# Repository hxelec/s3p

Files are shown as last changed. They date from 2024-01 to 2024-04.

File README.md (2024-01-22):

Haase Industries S3P boards: Arduino IDE code and KiCad schematic.

I'll comment the Arduino sketches properly in a few weeks, but,
meanwhile, ask me anything about the code or the schematic on my
YouTube video, and I'll be sure to respond to it.

Here's the video about this project:
https://youtu.be/9oY4NeJDy-g

Thanks to PCBWay for sponsoring this project! Get $5 of New User Free Credit by following this link - https://pcbway.com/g/x5f10h

PCBWay is one of the most experienced PCB manufacturers in China, consider them your one-stop solution that offers PCB fabrication, turn-key PCB Assembly, PCB design, 3D printing, and CNC machining services.

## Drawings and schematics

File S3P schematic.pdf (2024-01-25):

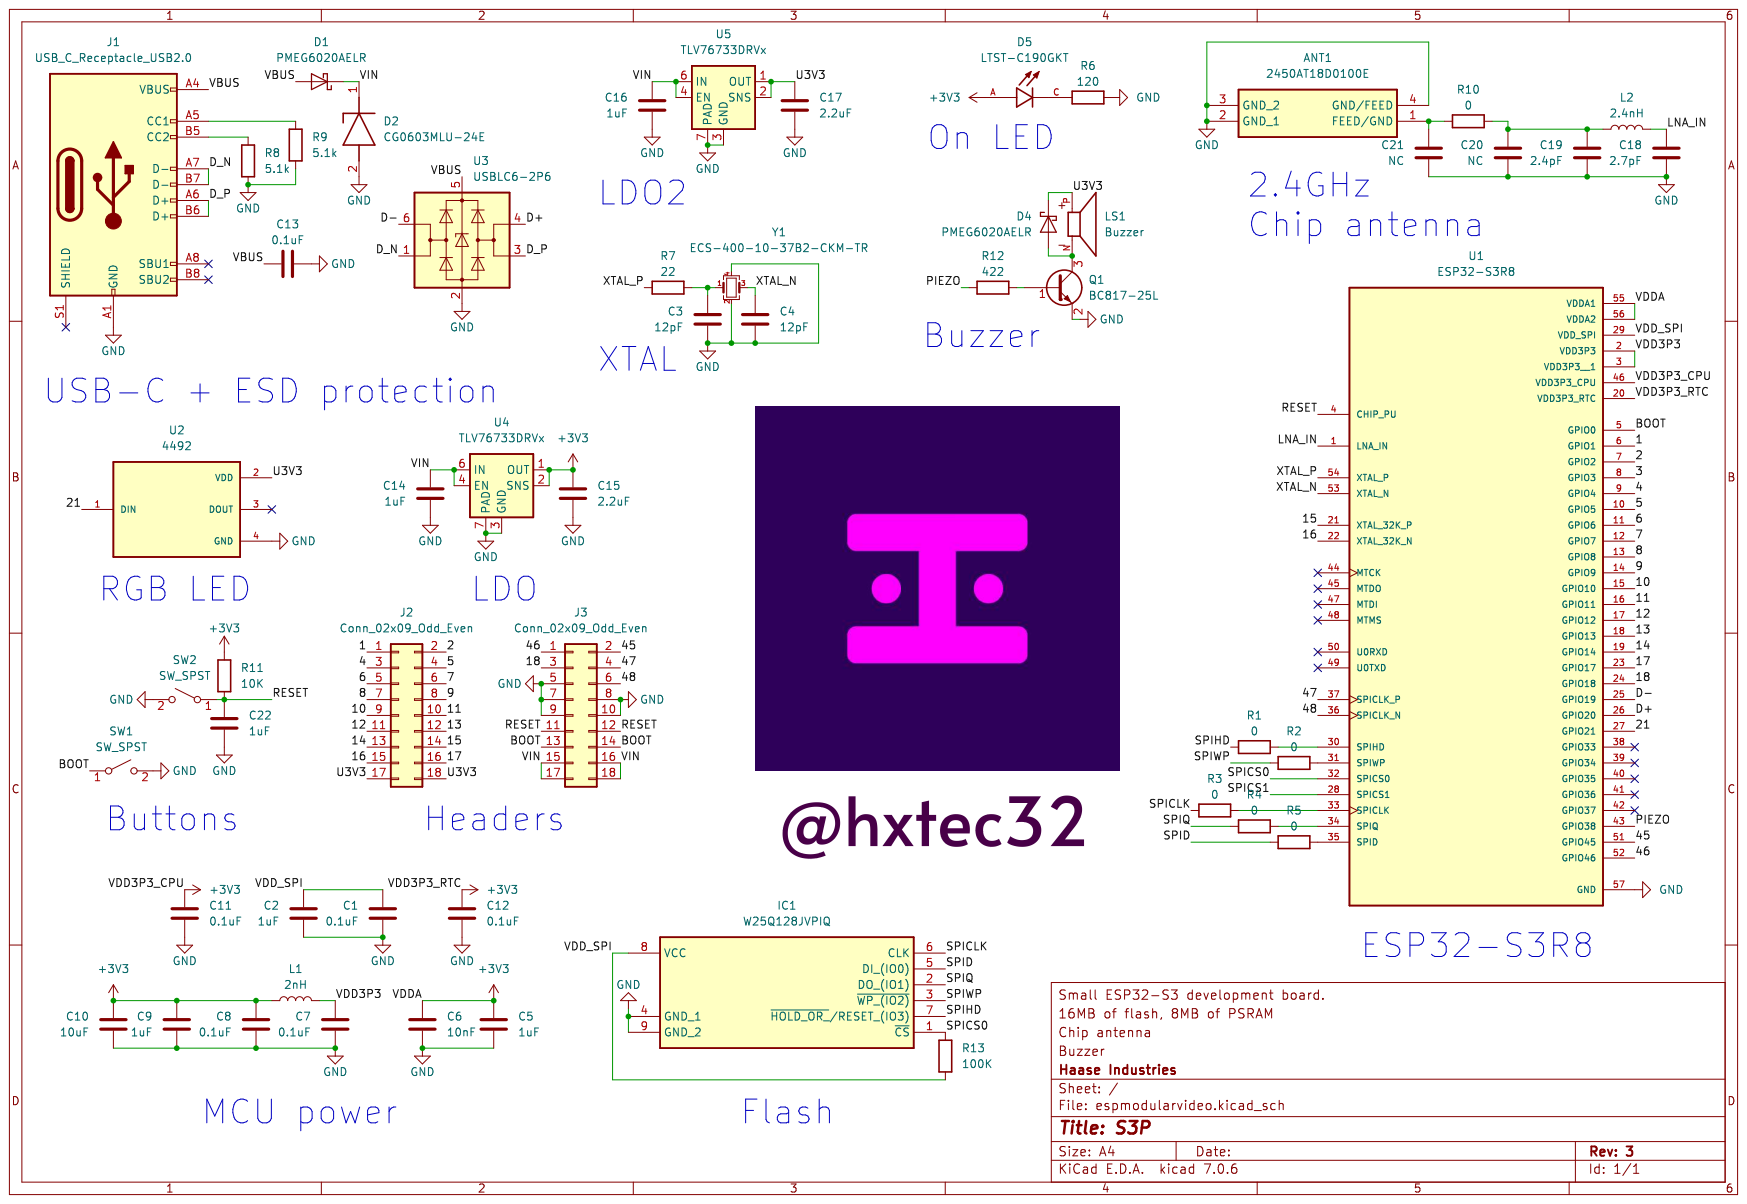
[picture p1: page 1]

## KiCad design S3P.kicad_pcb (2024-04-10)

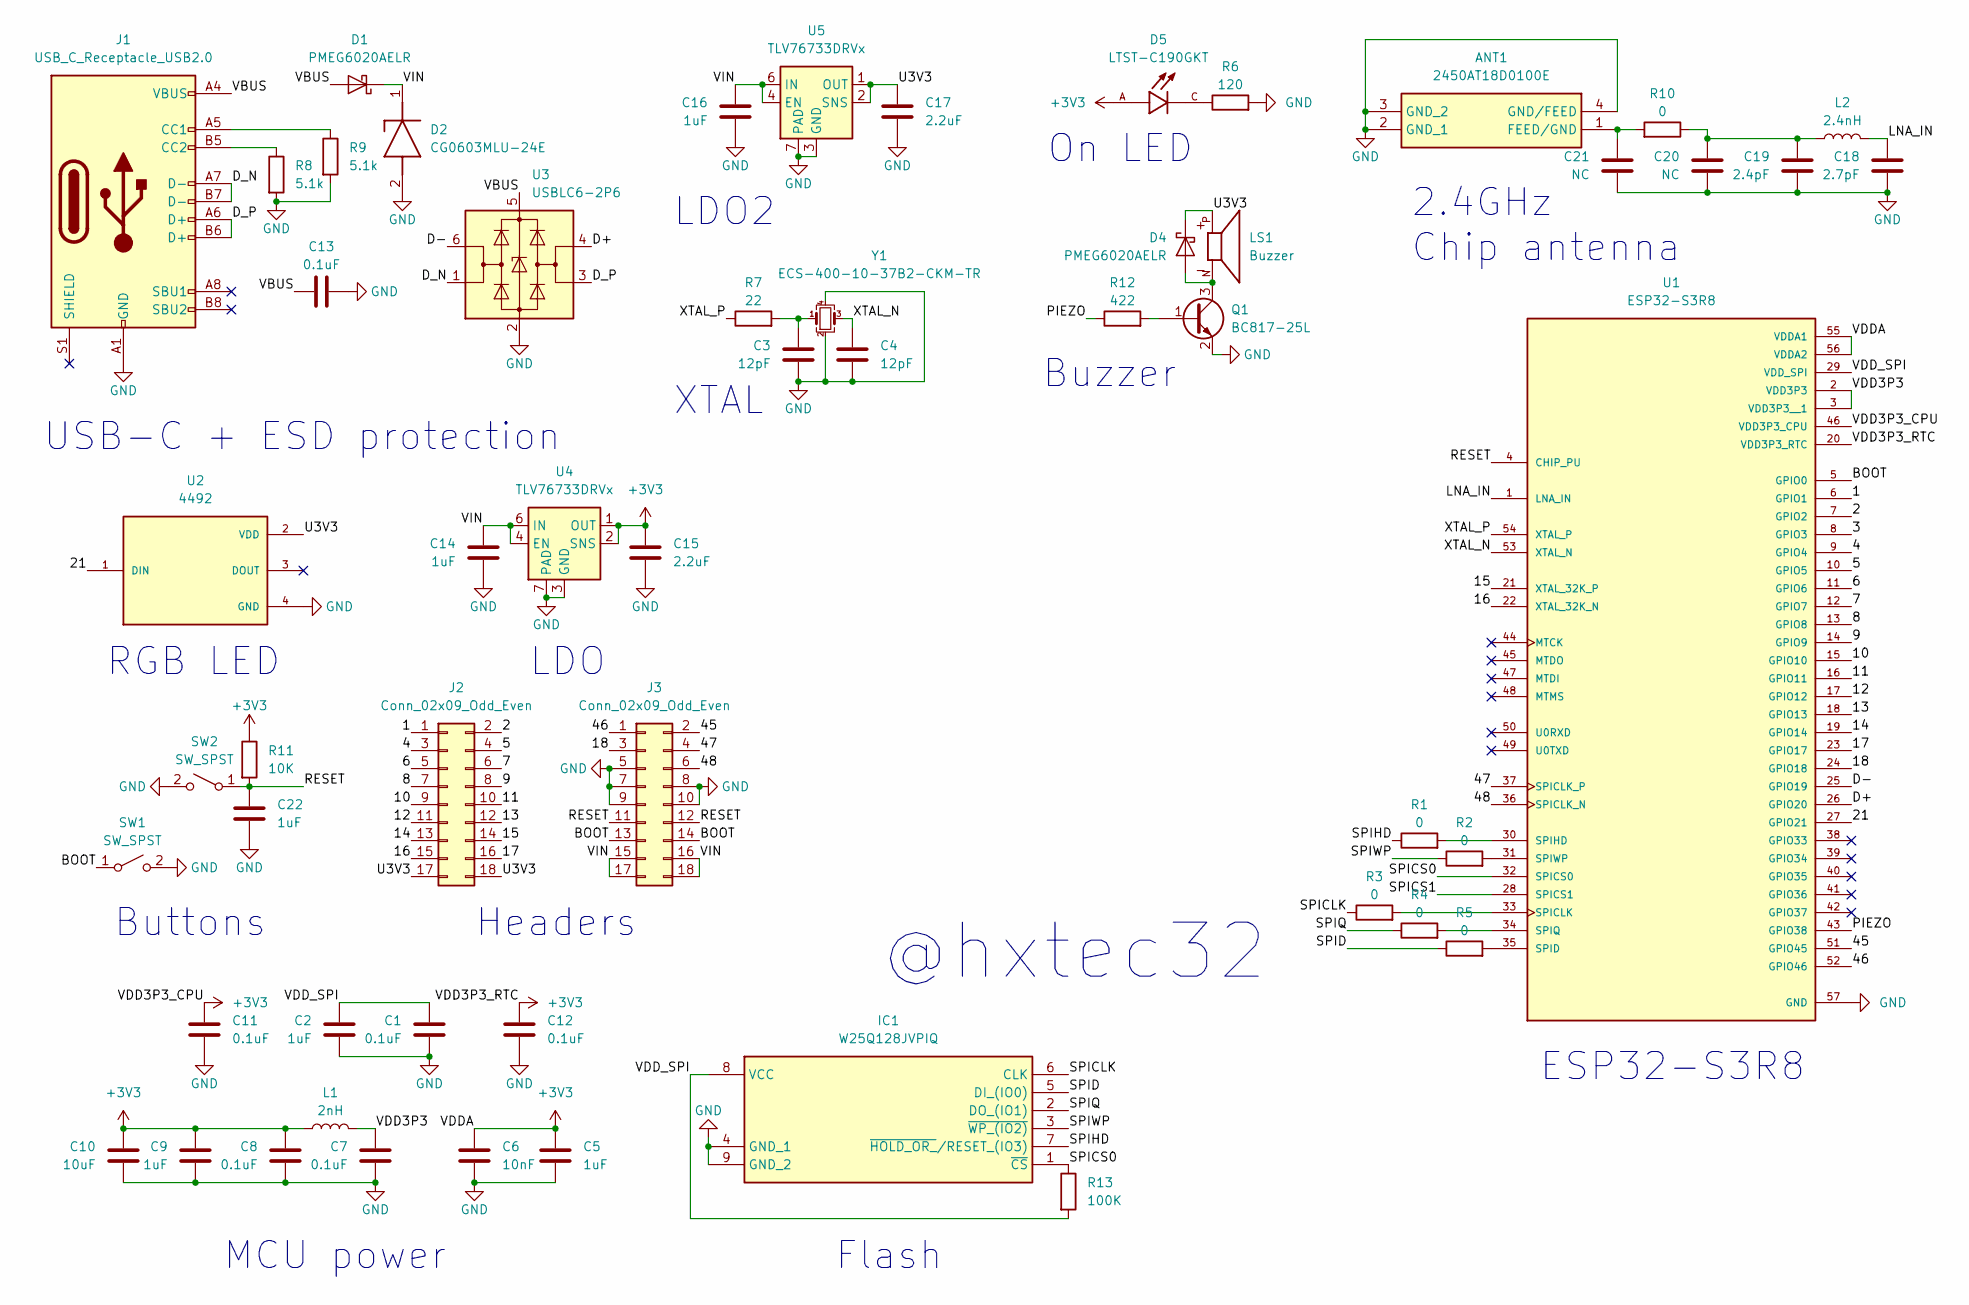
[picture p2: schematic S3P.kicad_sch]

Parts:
ANT1: 2450AT18D0100E; Manufacturer_Part_Number 2450AT18D0100E; Mouser Part Number 609-2450AT18D0100E
C1, C7, C8, C11, C12, C13: 0.1uF; R_0402_1005Metric
C2, C5, C9, C22: 1uF; R_0402_1005Metric
C3, C4: 12pF; R_0201_0603Metric
C6: 10nF; R_0201_0603Metric
C10: 10uF; R_0603_1608Metric
C14, C16: 1uF; R_0603_1608Metric
C15, C17: 2.2uF; R_0402_1005Metric
C18: 2.7pF; R_0201_0603Metric
C19: 2.4pF; R_0201_0603Metric
C20, C21: NC; R_0201_0603Metric
D1, D4: PMEG6020AELR; Nexperia_CFP3_SOD-123W
D2: CG0603MLU-24E; DIONC1608X55N; Manufacturer_Part_Number CG0603MLU-24E; Mouser Part Number 652-CG0603MLU-24E
D5: LTST-C190GKT; LEDC1608X35N
IC1: W25Q128JVPIQ; SON127P600X500X80-9N-D; Manufacturer_Part_Number W25Q128JVPIQ; Mouser Part Number 454-W25Q128JVPIQ
J1: USB_C_Receptacle_USB2.0; USB_C_Receptacle_GCT_USB4105-xx-A_16P_TopMnt_Horizontal
J2, J3: Conn_02x09_Odd_Even; PinHeader_2x09_P2.54mm_Vertical
L1: 2nH; L_0402_1005Metric
L2: 2.4nH; L_0201_0603Metric
LS1: Buzzer; XDCR_CMT-0525-75-SMT-TR; PARTREV 1.0
Q1: BC817-25L; SOT-23
R1, R2, R3, R4, R5, R10: 0; R_0201_0603Metric
R6: 120; R_0402_1005Metric
R7: 22; R_0402_1005Metric
R8, R9: 5.1k; R_0402_1005Metric
R11: 10K; R_0402_1005Metric
R12: 422; R_0402_1005Metric
R13: 100K; R_0201_0603Metric
SW1, SW2: SW_SPST; SW_SPST_PTS810
U1: ESP32-S3R8; QFN40P700X700X90-57N-D
U2: 4492; SK6805-EC15; PARTREV 14/10/19
U3: USBLC6-2P6; SOT-666
U4, U5: TLV76733DRVx; WSON-6-1EP_2x2mm_P0.65mm_EP1x1.6mm_ThermalVias
Y1: ECS-400-10-37B2-CKM-TR; Crystal_SMD_2016-4Pin_2.0x1.6mm

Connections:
+3V3: C5.1, C6.1, C8.1, C9.1, C10.1, C11.1, C12.1, C15.1, D5.A, L1.2, R11.1, U1.20 (VDD3P3_RTC), U1.46 (VDD3P3_CPU), U1.55 (VDDA1), U1.56 (VDDA2), U4.1 (OUT), U4.2 (SNS)
/1: J2.1, U1.6 (GPIO1)
/2: J2.2, U1.7 (GPIO2)
/3: U1.8 (GPIO3)
/4: J2.3, U1.9 (GPIO4)
/5: J2.4, U1.10 (GPIO5)
/6: J2.5, U1.11 (GPIO6)
/7: J2.6, U1.12 (GPIO7)
/8: J2.7, U1.13 (GPIO8)
/9: J2.8, U1.14 (GPIO9)
/10: J2.9, U1.15 (GPIO10)
/11: J2.10, U1.16 (GPIO11)
/12: J2.11, U1.17 (GPIO12)
/13: J2.12, U1.18 (GPIO13)
/14: J2.13, U1.19 (GPIO14)
/15: J2.14, U1.21 (XTAL_32K_P)
/16: J2.15, U1.22 (XTAL_32K_N)
/17: J2.16, U1.23 (GPIO17)
/18: J3.3, U1.24 (GPIO18)
/21: U1.27 (GPIO21), U2.1 (DIN)
/45: J3.2, U1.51 (GPIO45)
/46: J3.1, U1.52 (GPIO46)
/47: J3.4, U1.37 (SPICLK_P)
/48: J3.6, U1.36 (SPICLK_N)
/BOOT: J3.13, J3.14, SW1.1 (A), U1.5 (GPIO0)
/D+: U1.26 (GPIO20), U3.4 (I/O2)
/D-: U1.25 (GPIO19), U3.6 (I/O1)
/D_N: J1.A7 (D-), J1.B7 (D-), U3.1 (I/O1)
/D_P: J1.A6 (D+), J1.B6 (D+), U3.3 (I/O2)
/LNA_IN: C18.1, L2.1, U1.1 (LNA_IN)
/PIEZO: R12.1, U1.43 (GPIO38)
/RESET: C22.1, J3.11, J3.12, R11.2, SW2.1 (A), U1.4 (CHIP_PU)
/SPICLK: IC1.6 (CLK), R3.1
/SPICS0: IC1.1 (~CS), R13.1, U1.32 (SPICS0)
/SPICS1: U1.28 (SPICS1)
/SPID: IC1.5 (DI_(IO0)), R5.1
/SPIHD: IC1.7 (~HOLD_OR_/RESET_(IO3)), R1.1
/SPIQ: IC1.2 (DO_(IO1)), R4.1
/SPIWP: IC1.3 (~WP_(IO2)), R2.1
/U3V3: C17.1, D4.1 (K), J2.17, J2.18, LS1.P, U2.2 (VDD), U5.1 (OUT), U5.2 (SNS)
/VBUS: C13.1, D1.2 (A), J1.A4 (VBUS), J1.A9 (VBUS), J1.B4 (VBUS), J1.B9 (VBUS), U3.5 (VBUS)
/VDD3P3: C7.1, L1.1, U1.2 (VDD3P3), U1.3 (VDD3P3__1)
/VDD_SPI: C1.1, C2.1, IC1.8 (VCC), R13.2, U1.29 (VDD_SPI)
/VIN: C14.1, C16.1, D1.1 (K), D2.1 (K), J3.15, J3.16, J3.17, J3.18, U4.4 (EN), U4.6 (IN), U5.4 (EN), U5.6 (IN)
/XTAL_N: C4.1, U1.53 (XTAL_N), Y1.3
/XTAL_P: R7.1, U1.54 (XTAL_P)
GND: ANT1.2 (GND_1), ANT1.3 (GND_2), ANT1.4 (GND/FEED), C1.2, C2.2, C3.2, C4.2, C5.2, C6.2, C7.2, C8.2, C9.2, C10.2, C11.2, C12.2, C13.2, C14.2, C15.2, C16.2, C17.2, C18.2, C19.2, C20.2, C21.2, C22.2, D2.2 (A), IC1.4 (GND_1), IC1.9 (GND_2), J1.A1 (GND), J1.A12 (GND), J1.B1 (GND), J1.B12 (GND), J3.5, J3.7, J3.8, J3.9, J3.10, Q1.2 (E), R6.2, R8.2, R9.2, SW1.2 (B), SW2.2 (B), U1.57 (GND), U2.4 (GND), U3.2 (GND), U4.3 (GND), U4.5 (GND), U4.7 (PAD), U5.3 (GND), U5.5 (GND), U5.7 (PAD), Y1.2, Y1.4
unnamed: ANT1.1 (FEED/GND), C21.1, R10.2
unnamed: C3.1, R7.2, Y1.1
unnamed: C19.1, C20.1, L2.2, R10.1
unnamed: D4.2 (A), LS1.N, Q1.3 (C)
unnamed: D5.C, R6.1
unnamed: J1.A5 (CC1), R9.1
unnamed: J1.B5 (CC2), R8.1
unnamed: Q1.1 (B), R12.2
unnamed: R3.2, U1.33 (SPICLK)
unnamed: R5.2, U1.35 (SPID)
unnamed: R1.2, U1.30 (SPIHD)
unnamed: R4.2, U1.34 (SPIQ)
unnamed: R2.2, U1.31 (SPIWP)

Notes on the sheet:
LDO
Buzzer
Buttons
RGB LED
Flash
USB-C + ESD protection
Chip antenna
Headers
XTAL
@hxtec32
MCU power
On LED
2.4GHz
ESP32-S3R8
LDO2

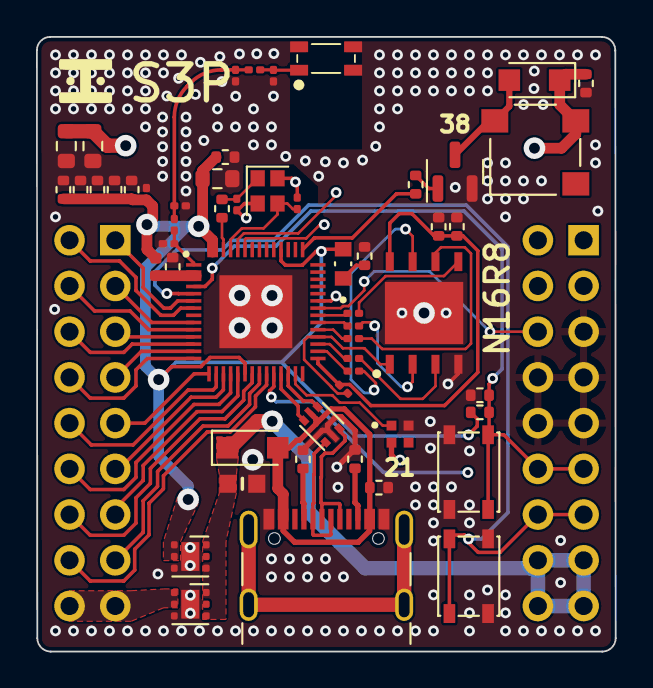
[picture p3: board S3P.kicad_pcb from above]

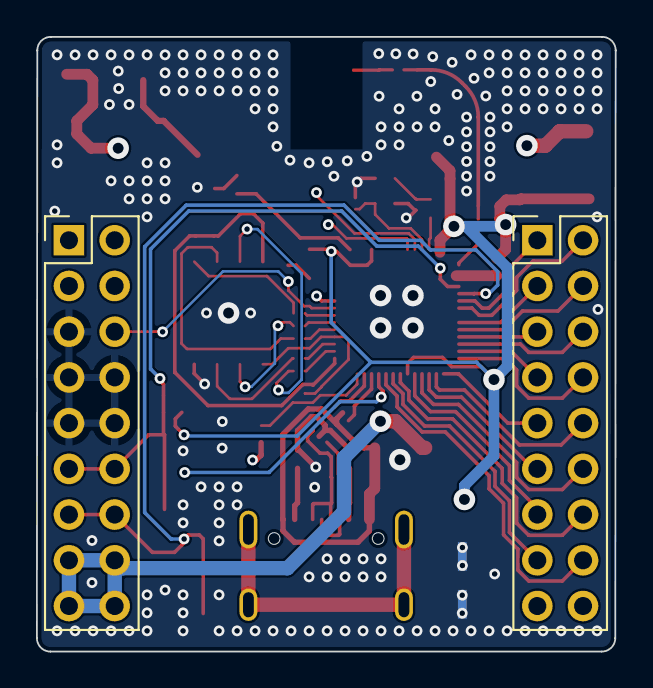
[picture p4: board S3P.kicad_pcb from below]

Board: 4 copper layers, 32.2 x 34.1 mm, 56 parts (2 on the bottom side), 58 nets.

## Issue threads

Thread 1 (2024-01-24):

KiCad Files

antimatter15, 2024-01-24:
It looks like the Kicad schematic files are mentioned in the README but they aren't in the repo, were they not uploaded by accident?

hxelec, 2024-01-25:
Oh, yeah. I just uploaded them, sorry about that.

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

antimatter15, 2024-01-25:
Thanks! Also in a few years you should consider applying to MIT, we would be lucky to have you!

hxelec, 2024-01-25:
Thanks! Yeah, I probably will, that would be really awesome.

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

Closed 2024-01-25.

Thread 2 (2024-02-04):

License

SoupySoups, 2024-02-04:
There is no license in this repository. With the fact that this is a WIP, what terms would you like this schematic to be used under?

For my use case am I specifically asking about use with modification and attribution for non-commercial use.

hxelec, 2024-02-05:
Hi Camden,

Sure, you can do that. Sorry for the late reply, I’d be happy for you to
make a board for non-commercial use with attribution. Please let me know
when you are done making it, would love to see it! I’ll add a license into
this GitHub now, thanks.

On Sun, 4 Feb 2024 at 11:29 am, Camden Adams ***@***.***>
wrote:

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

SoupySoups, 2024-03-13:
Thanks so much :)

Closed 2024-03-13.

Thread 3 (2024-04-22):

Schematic Question

AzonInc, 2024-04-22:
Hi,

did u change anything about the second antenna matching circuit as its still NC in the schematic?
Would be interesting to know if it works without that.

Best regards

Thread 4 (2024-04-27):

Could you please share your Bill of Materials and the Postions file

aaryavbehl, 2024-04-27:
Hey!
I was trying to order this cool PCB of yours from my local vendor, doing so I realised that my BOM and positions and are coming out all gibberish(corrupted probably). I tried it again and again but it seems like my KiCAD is bugging out.

aaryavbehl, 2024-04-27:
it would be delightful if you could share me your Bill of materials and the positions file so I can get it ordered

Thanks

Closed 2024-05-03.

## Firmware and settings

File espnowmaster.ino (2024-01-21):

#include <Adafruit_NeoPixel.h>

/*
  Rui Santos
  Complete project details at https://RandomNerdTutorials.com/esp-now-esp32-arduino-ide/
  
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
  The above copyright notice and this permission notice shall be included in all
  copies or substantial portions of the Software.
*/

#include <esp_now.h>
#include <WiFi.h>

Adafruit_NeoPixel pixels(1, 21, NEO_GRB + NEO_KHZ800);

// REPLACE WITH YOUR RECEIVER MAC Address
uint8_t broadcastAddress[] = {0xDC, 0xDA, 0x0C, 0x2A, 0x4E, 0xC0};

// Structure example to send data
// Must match the receiver structure
typedef struct struct_message {
  int a;
  int b;
} struct_message;

// Create a struct_message called myData
struct_message myData;

esp_now_peer_info_t peerInfo;

bool connect = true;

// callback when data is sent
void OnDataSent(const uint8_t *mac_addr, esp_now_send_status_t status) {
  Serial.print("\r\nLast Packet Send Status:\t");
  Serial.println(status == ESP_NOW_SEND_SUCCESS ? "Delivery Success" : "Delivery Fail");
}
 
void setup() {
  // Init Serial Monitor
  Serial.begin(115200);
 
  pixels.begin();
  pixels.setBrightness(100);

  // Set device as a Wi-Fi Station
  WiFi.mode(WIFI_STA);

  // Init ESP-NOW
  if (esp_now_init() != ESP_OK) {
    Serial.println("Error initializing ESP-NOW");
    return;
  }

  // Once ESPNow is successfully Init, we will register for Send CB to
  // get the status of Trasnmitted packet
  esp_now_register_send_cb(OnDataSent);
  
  // Register peer
  memcpy(peerInfo.peer_addr, broadcastAddress, 6);
  peerInfo.channel = 0;  
  peerInfo.encrypt = false;
  
  // Add peer        
  if (esp_now_add_peer(&peerInfo) != ESP_OK){
    Serial.println("Failed to add peer");
    return;
  }
}
 
void loop() {
  if (connect = true) {
    pixels.fill(0xFF0000);
    pixels.show();
    // Set values to send
    myData.a = 1175; //note frequency
    myData.b = 200; //note duration
    
    // Send message via ESP-NOW
    esp_err_t result = esp_now_send(broadcastAddress, (uint8_t *) &myData, sizeof(myData));

    tone(38, 1397, 140);
    pixels.fill(0x000000);
    pixels.show();
    delay(200);
    noTone(38);

    pixels.fill(0xFF0000);
    pixels.show();
      // Set values to send
    myData.a = 1175; //note frequency
    myData.b = 200; //note duration
    
    // Send message via ESP-NOW
    result = esp_now_send(broadcastAddress, (uint8_t *) &myData, sizeof(myData));

    tone(38, 1397, 140);
    pixels.fill(0x000000);
    pixels.show();
    delay(200);
    noTone(38);

    delay(400);

    pixels.fill(0x008000);
    pixels.show();
    tone(38, 1568, 300);
    tone(38, 1760, 70);
    delay(400);
    tone(38, 1760, 100);
    tone(38, 1568, 210);
    pixels.fill(0x000000);
    pixels.show();
    delay(400);

    pixels.fill(0xFF0000);
    pixels.show();
    // Set values to send
    myData.a = 1047; //note frequency
    myData.b = 200; //note duration
    
    // Send message via ESP-NOW
    result = esp_now_send(broadcastAddress, (uint8_t *) &myData, sizeof(myData));

    tone(38, 1319, 140);
    pixels.fill(0x000000);
    pixels.show();
    delay(200);
    noTone(38);

    pixels.fill(0xFF0000);
    pixels.show();
      // Set values to send
    myData.a = 1047; //note frequency
    myData.b = 200; //note duration
    
    // Send message via ESP-NOW
    result = esp_now_send(broadcastAddress, (uint8_t *) &myData, sizeof(myData));

    tone(38, 1319, 140);
    pixels.fill(0x000000);
    pixels.show();
    delay(200);
    noTone(38);

    delay(400);

    pixels.fill(0x008000);
    pixels.show();
    tone(38, 2093, 400);
    tone(38, 1865, 100);
    tone(38, 1760, 210);
    pixels.fill(0x000000);
    pixels.show();
    delay(800);

    pixels.fill(0xFF0000);
    pixels.show();
    // Set values to send
    myData.a = 932; //note frequency
    myData.b = 200; //note duration
    
    // Send message via ESP-NOW
    result = esp_now_send(broadcastAddress, (uint8_t *) &myData, sizeof(myData));

    tone(38, 1175, 140);
    pixels.fill(0x000000);
    pixels.show();
    delay(200);
    noTone(38);

    pixels.fill(0xFF0000);
    pixels.show();
      // Set values to send
    myData.a = 932; //note frequency
    myData.b = 200; //note duration
    
    // Send message via ESP-NOW
    result = esp_now_send(broadcastAddress, (uint8_t *) &myData, sizeof(myData));

    tone(38, 1175, 140);
    pixels.fill(0x000000);
    pixels.show();
    delay(200);
    noTone(38);

    pixels.fill(0x008000);
    pixels.show();
    tone(38, 1865, 100);
    tone(38, 1760, 100);
    tone(38, 1568, 100);
    tone(38, 1397, 100);
    tone(38, 1568, 300);
    tone(38, 1760, 70);
    pixels.fill(0x000000);
    pixels.show();
    delay(800);
    pixels.fill(0x008000);
    pixels.show();
    tone(38, 1760, 100);
    tone(38, 1568, 210);
    pixels.fill(0x000000);
    pixels.show();
    delay(400);

    pixels.fill(0xFF0000);
    pixels.show();
    // Set values to send
    myData.a = 1047; //note frequency
    myData.b = 200; //note duration
    
    // Send message via ESP-NOW
    result = esp_now_send(broadcastAddress, (uint8_t *) &myData, sizeof(myData));

    tone(38, 1568, 140);
    pixels.fill(0x000000);
    pixels.show();
    delay(200);
    noTone(38);

    pixels.fill(0xFF0000);
    pixels.show();
      // Set values to send
    myData.a = 1047; //note frequency
    myData.b = 200; //note duration
    
    // Send message via ESP-NOW
    result = esp_now_send(broadcastAddress, (uint8_t *) &myData, sizeof(myData));

    tone(38, 1568, 140);
    pixels.fill(0x000000);
    pixels.show();
    delay(200);
    noTone(38);

    delay(400);

    pixels.fill(0xFF0000);
    pixels.show();
    // Set values to send
    myData.a = 1109; //note frequency
    myData.b = 200; //note duration
    
    // Send message via ESP-NOW
    result = esp_now_send(broadcastAddress, (uint8_t *) &myData, sizeof(myData));

    tone(38, 1319, 140);
    pixels.fill(0x000000);
    pixels.show();
    delay(200);
    noTone(38);

    pixels.fill(0xFF0000);
    pixels.show();
      // Set values to send
    myData.a = 1109; //note frequency
    myData.b = 200; //note duration
    
    // Send message via ESP-NOW
    result = esp_now_send(broadcastAddress, (uint8_t *) &myData, sizeof(myData));

    tone(38, 1319, 140);
    pixels.fill(0x000000);
    pixels.show();
    delay(200);
    noTone(38);

    delay(400);
  }
}

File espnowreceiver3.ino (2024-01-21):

#include <ESP32Servo.h>
#include <Adafruit_NeoPixel.h>

/*
  Rui Santos
  Complete project details at https://RandomNerdTutorials.com/esp-now-esp32-arduino-ide/
  
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
  The above copyright notice and this permission notice shall be included in all
  copies or substantial portions of the Software.
*/

#include <esp_now.h>
#include <WiFi.h>


int pos = 0;

Adafruit_NeoPixel pixels(1, 21, NEO_GRB + NEO_KHZ800);

Servo myservo;

bool action = false;

// Structure example to receive data
// Must match the sender structure
typedef struct struct_message {
  bool a;
} struct_message;

// Create a struct_message called myData
struct_message myData;

// callback function that will be executed when data is received
void OnDataRecv(const uint8_t * mac, const uint8_t *incomingData, int len) {
  memcpy(&myData, incomingData, sizeof(myData));
  if (myData.a == true) {
    pixels.fill(0x008000);
    pixels.show();
    myservo.write(180);
  } else {
    pixels.fill(0x000000);
    pixels.show();
    myservo.write(0);
  }
}
 
void setup() {
  // Initialize Serial Monitor
  Serial.begin(115200);

	ESP32PWM::allocateTimer(0);
	ESP32PWM::allocateTimer(1);
	ESP32PWM::allocateTimer(2);
	ESP32PWM::allocateTimer(3);
	myservo.setPeriodHertz(50);    // standard 50 hz servo
	myservo.attach(2, 1000, 2000); // attaches the servo on pin 2 to the servo object

  pixels.begin();
  pixels.setBrightness(100);
  
  // Set device as a Wi-Fi Station
  WiFi.mode(WIFI_STA);

  // Init ESP-NOW
  if (esp_now_init() != ESP_OK) {
    Serial.println("Error initializing ESP-NOW");
    return;
  }
  
  // Once ESPNow is successfully Init, we will register for recv CB to
  // get recv packer info
  esp_now_register_recv_cb(OnDataRecv);
}
 
void loop() {

}

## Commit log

2024-01-25 Add files via upload
    oopsies, sorry for forgetting to upload the schematic
2024-04-10 KICAD FILES
    [espmodularvideo.kicad_pcb, espmodularvideo.kicad_sch]
2024-04-10 Update and rename espmodularvideo.kicad_pcb to S3P.kicad_pcb
    [S3P.kicad_pcb]
2024-04-10 Update and rename espmodularvideo.kicad_sch to S3P.kicad_sch
    [S3P.kicad_sch]
